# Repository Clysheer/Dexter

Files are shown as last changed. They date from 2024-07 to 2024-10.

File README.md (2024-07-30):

# Dexter
El proyecto consiste en la construcción de un robot autónomo capaz de navegar por un laberinto utilizando una combinación de hardware y software especializado. El robot estará equipado con un sensor de distancia VL6180X, el cual será fundamental para detectar obstáculos y calcular distancias mientras se desplaza por el laberinto. Este sensor permitirá al robot tomar decisiones informadas sobre la dirección a seguir para evitar colisiones y encontrar la ruta más eficiente hacia la salida del laberinto.
Para controlar los movimientos del robot, se utilizarán motores Pololu de 6V, los cuales serán gestionados por un driver TA 6586. Este driver proporcionará la potencia necesaria para que los motores puedan desplazar el robot con precisión y control, permitiéndole moverse de manera suave y estable a través del laberinto.
La placa microprocesadora ESP32 será el cerebro del robot, encargada de procesar los datos del sensor de distancia y tomar decisiones en tiempo real para guiar al robot por el laberinto. Esta placa estará programada con algoritmos de navegación y control que permitirán al robot realizar maniobras complejas, como girar en esquinas y evitar obstáculos, con el objetivo de encontrar la salida del laberinto de la manera más rápida y eficiente posible.
Además, para garantizar la autonomía del robot durante su recorrido por el laberinto, se utilizará una batería de 600 miliamperios a 7.4 voltios. Esta batería proporcionará la energía necesaria para alimentar todos los componentes del robot, asegurando que pueda completar su misión sin interrupciones.

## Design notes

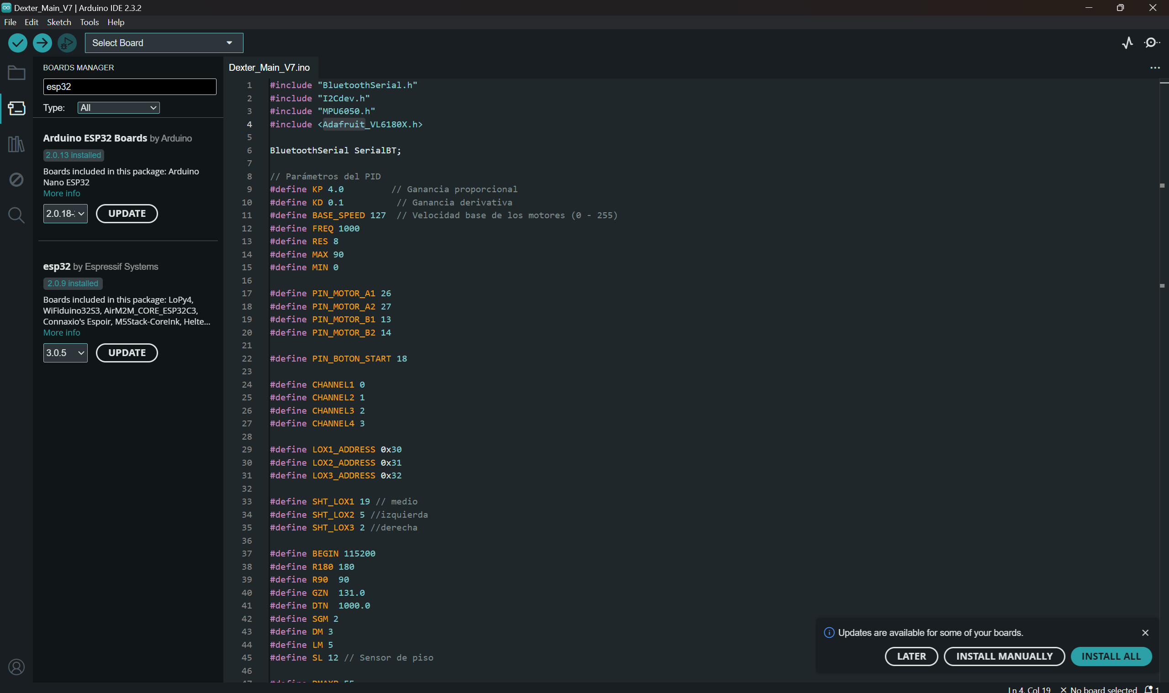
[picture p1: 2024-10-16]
Dexter_main/Dexter_Main_V7/BOARDMANAGE_ESP32.png

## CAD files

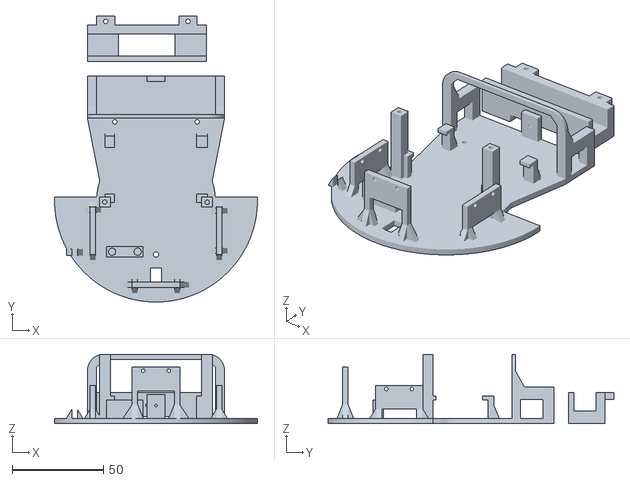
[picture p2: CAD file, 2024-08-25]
Dexter_3D/dexter v1.stl
111.0 x 156.4 x 38.0

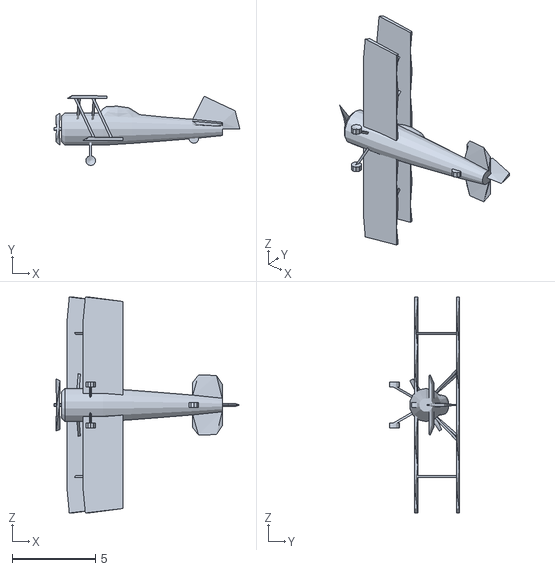
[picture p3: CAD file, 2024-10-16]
Dexter_Liberias/VL6180X/i2c_libreria/MPU6050/examples/MPU6050_DMP6_using_DMP_V6.12/MPUplane/data/biplane.obj
11.2 x 4.23 x 13.0

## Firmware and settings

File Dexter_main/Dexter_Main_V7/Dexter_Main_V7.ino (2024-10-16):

#include "BluetoothSerial.h"
#include "I2Cdev.h"
#include "MPU6050.h"
#include <Adafruit_VL6180X.h>
 
BluetoothSerial SerialBT;

// Parámetros del PID
#define KP 4.0         // Ganancia proporcional
#define KD 0.1          // Ganancia derivativa
#define BASE_SPEED 127  // Velocidad base de los motores (0 - 255)
#define FREQ 1000
#define RES 8
#define MAX 90
#define MIN 0

#define PIN_MOTOR_A1 26
#define PIN_MOTOR_A2 27
#define PIN_MOTOR_B1 13
#define PIN_MOTOR_B2 14

#define PIN_BOTON_START 18

#define CHANNEL1 0
#define CHANNEL2 1
#define CHANNEL3 2
#define CHANNEL4 3

#define LOX1_ADDRESS 0x30
#define LOX2_ADDRESS 0x31
#define LOX3_ADDRESS 0x32

#define SHT_LOX1 19 // medio
#define SHT_LOX2 5 //izquierda
#define SHT_LOX3 2 //derecha

#define BEGIN 115200
#define R180 180
#define R90  90
#define GZN  131.0
#define DTN  1000.0
#define SGM 2
#define DM 3
#define LM 5
#define SL 12 // Sensor de piso

#define DMAXP 55
#define DMAXD 85
#define DMAXI 80
#define DMAXM 100
#define DISTANCE1 0 
#define DISTANCE2 1 //
#define DISTANCE3 2 //izquierda
#define SCL 22
#define SDA 21

MPU6050 sensor;
  int16_t distance[DM] = {DISTANCE1, DISTANCE2,DISTANCE3};  // Arreglo para las distancias de los sensores (distance1, distance2,distance3)
  int16_t *dr = distance;


  // Valor RAW del giroscopio en el eje z
  int16_t gz;
  int16_t gy;
  int16_t gx;
  float gz_cal=0;
  long tiempo_prev, dt;
  float elapsedTime;
  float girosc_ang_z;
  float girosc_ang_z_prev;
  float angleZ = 0;  

  Adafruit_VL6180X lox1 = Adafruit_VL6180X();
  Adafruit_VL6180X lox2 = Adafruit_VL6180X();
  Adafruit_VL6180X lox3 = Adafruit_VL6180X();

  bool boton_presionado = false;
  float previousError = 0;


// Función de reposo
void reposo() {
  while (!boton_presionado) {
    if (digitalRead(PIN_BOTON_START) == LOW) {
      boton_presionado = true;
      delay(200);  // Anti-rebote
    }
  }
}

// Configurar los ID de los sensores

void setID() {
  digitalWrite(SHT_LOX1, LOW);
  digitalWrite(SHT_LOX2, LOW);
  digitalWrite(SHT_LOX3, LOW);
  delay(10);
  digitalWrite(SHT_LOX1, HIGH);
  digitalWrite(SHT_LOX2, HIGH);
  digitalWrite(SHT_LOX3, HIGH);
  delay(10);
  digitalWrite(SHT_LOX1, HIGH);
  digitalWrite(SHT_LOX2, LOW);
  digitalWrite(SHT_LOX3, LOW);
  Serial.println("no entro jajajaja");
 if (!lox1.begin()) while (1);
  lox1.setAddress(LOX1_ADDRESS);
  delay(10);
  Serial.println("A");
  digitalWrite(SHT_LOX2, HIGH);
  delay(10);

  if (!lox2.begin()) while (1);
  lox2.setAddress(LOX2_ADDRESS);
  digitalWrite(SHT_LOX3, HIGH);
  delay(10); 
  Serial.println("B");
  if (!lox3.begin()) while (1);
  lox3.setAddress(LOX3_ADDRESS);
  Serial.println("C");
}

void start_sensors() {
  sensor.initialize();  // Inicializa el MPU6050
  pinMode(PIN_BOTON_START, INPUT_PULLUP);
  pinMode(SHT_LOX1, OUTPUT);
  pinMode(SHT_LOX2, OUTPUT);
  pinMode(SHT_LOX3, OUTPUT);
  setID();
  calibrateMPU6050();
  tiempo_prev = millis();
  // Configuración de los pines de los motores
  ledcAttachPin(PIN_MOTOR_A1, CHANNEL1);
  ledcSetup(CHANNEL1, FREQ, RES);
  ledcAttachPin(PIN_MOTOR_A2, CHANNEL2);
  ledcSetup(CHANNEL2, FREQ, RES);
  ledcAttachPin(PIN_MOTOR_B1, CHANNEL3);
  ledcSetup(CHANNEL3, FREQ, RES);
  ledcAttachPin(PIN_MOTOR_B2, CHANNEL4);
  ledcSetup(CHANNEL4, FREQ, RES);
}

void readDistance(Adafruit_VL6180X &vl, uint16_t &distance) {
  uint16_t range = vl.readRange();
  distance = range;
}

void measurement(int16_t *dr) {
  uint16_t distance1, distance2, distance3;
  readDistance(lox1, distance1);
  *dr = distance1;
  readDistance(lox2, distance2);
  *(dr + 1) = distance2;
  readDistance(lox3, distance3);
  *(dr+ 2) = distance3;
}

void moveForward() {
  ledcWrite(CHANNEL1, MAX -45);  
  ledcWrite(CHANNEL2, MIN);
  ledcWrite(CHANNEL3, MAX);  
  ledcWrite(CHANNEL4, MIN);
}

void stopMotors() {
  ledcWrite(CHANNEL1, MIN);
  ledcWrite(CHANNEL2, MIN);
  ledcWrite(CHANNEL3, MIN);
  ledcWrite(CHANNEL4, MIN);
}
void moveLeft() {
  ledcWrite(CHANNEL1, MAX); 
  ledcWrite(CHANNEL2, MIN);
  ledcWrite(CHANNEL3, MIN);   
  ledcWrite(CHANNEL4, MAX);
}

void moveRight() {
  ledcWrite(CHANNEL1, MIN);   
  ledcWrite(CHANNEL2, MAX);
  ledcWrite(CHANNEL3, MAX);  
  ledcWrite(CHANNEL4, MIN);
}

// PID para el sensor VL6180X
void pidControl() {
  float error, derivative, pidOutput;

  error = DMAXP - distance[DISTANCE2];
  derivative = error - previousError;
  pidOutput = (KP * error) + (KD * derivative);
  previousError = error;

  int motorSpeedLeft = constrain(BASE_SPEED + pidOutput, MIN, MAX);
  int motorSpeedRight = constrain(BASE_SPEED - pidOutput, MIN, MAX);

  controlMotor(motorSpeedLeft, motorSpeedRight);
  delay(100);
}

void controlMotor(int speedLeft, int speedRight) {
  if (speedLeft > 0) {
    ledcWrite(CHANNEL1, speedLeft - 45);  
    ledcWrite(CHANNEL2, MIN);       
  } else {
    ledcWrite(CHANNEL1, MIN);       
    ledcWrite(CHANNEL2, abs(speedLeft)- 45);  
  }

  if (speedRight > 0) {
    ledcWrite(CHANNEL3, speedRight ); 
    ledcWrite(CHANNEL4, MIN);       
  } else {
    ledcWrite(CHANNEL3, MIN);       
    ledcWrite(CHANNEL4, abs(speedRight) );  
  }
}

// Función para rotar a un ángulo específico
void RRight(float degrees) {
  // Capturar el ángulo actual antes de rotar
  float targetAngle;  
  sensor.getRotation(&gx, &gy, &gz);
  angleZ += (gz - gz_cal) * (1.0 / 131.0); // Actualizar el ángulo acumulado
  targetAngle = angleZ + degrees; // Establecer el ángulo objetivo
  rotateRight();
  // Esperar hasta alcanzar el ángulo objetivo
  while (true) {
    sensor.getRotation(&gx, &gy, &gz);
    angleZ += (gz - gz_cal) * (1.0 / 131.0); // Actualizar el ángulo acumulado

    // Comprobar si se ha alcanzado el ángulo objetivo
    if ((degrees > 0 && angleZ >= targetAngle) || (degrees < 0 && angleZ <= targetAngle)) {
      stopMotors();
      break;
    }

    // Imprimir el ángulo actual
    Serial.print("Ángulo actual: ");
    Serial.println(angleZ);
    delay(100); // Espera un momento para evitar sobrecargar el serial
  }
}

void RLeft(float degrees) {
  // Capturar el ángulo actual antes de rotar
  float targetAngle;  
  sensor.getRotation(&gx, &gy, &gz);
  angleZ += (gz - gz_cal) * (1.0 / 131.0); // Actualizar el ángulo acumulado
  targetAngle = angleZ + degrees; // Establecer el ángulo objetivo
  rotateLeft();
  // Esperar hasta alcanzar el ángulo objetivo
  while (true) {
    sensor.getRotation(&gx, &gy, &gz);
    angleZ += (gz - gz_cal) * (1.0 / 131.0); // Actualizar el ángulo acumulado

    // Comprobar si se ha alcanzado el ángulo objetivo
    if ((degrees > 0 && angleZ >= targetAngle) || (degrees < 0 && angleZ <= targetAngle)) {
      stopMotors();
      break;
    }

    // Imprimir el ángulo actual
    Serial.print("Ángulo actual: ");
    Serial.println(angleZ);
    delay(100); // Espera un momento para evitar sobrecargar el serial
  }
}
// Función para girar a la derecha
void rotateRight() {
  ledcWrite(CHANNEL1, MIN); 
  ledcWrite(CHANNEL2, MAX);
  ledcWrite(CHANNEL3, MAX - 55);   
  ledcWrite(CHANNEL4, MIN);
  SerialBT.println("Girando a la derecha");
}

// Función para girar a la izquierda
void rotateLeft() {
  ledcWrite(CHANNEL1, MAX); 
  ledcWrite(CHANNEL2, MIN);
  ledcWrite(CHANNEL3, MIN);   
  ledcWrite(CHANNEL4, MAX - 55);
  SerialBT.println("Girando a la izquierda");
}

void calibrateMPU6050() {
  const int calibrations = 2000;
  float sumGz = 0;

  Serial.println("Calibrando el MPU6050...");
  for (int i = 0; i < calibrations; i++) {
    sensor.getRotation(&gx, &gy, &gz);
    sumGz += gz;
    delay(3);
  }
  gz_cal = sumGz / calibrations;
  Serial.println("Calibración completada.");
}
enum estadosMovimiento
{
  PISODETECTADO,
  MOVEFORWARD,
  ROTATEL90,
  ROTATER90,
  ROTATE180
};

void movements() { 
    int8_t piso = digitalRead(SL);
    estadosMovimiento state; 
    measurement(distance);
    if (piso == HIGH){  
        SerialBT.println("Entrando en caso: PISODETECTADO");
        state = PISODETECTADO;  //detecta piso
    }
    else if (distance[DISTANCE3] > DMAXI && distance[DISTANCE1] > DMAXM && distance[DISTANCE2] < DMAXD  ) { 
        SerialBT.println("Entrando en caso: MOVEFORWARD");  //detecta derecha
        state =  MOVEFORWARD ;   
    }
    else if (distance[DISTANCE3] > DMAXI && distance[DISTANCE1] < DMAXM && distance[DISTANCE2] < DMAXD ) {  
        SerialBT.println("Entrando en caso: ROTATEL90");//detectan medio y derecha 
        state = ROTATEL90 ;  //rotatel90 
    }
   else if (distance[DISTANCE3] < DMAXI && distance[DISTANCE1] > DMAXM && distance[DISTANCE2] < DMAXD ) { 
        SerialBT.println("Entrando en caso: MOVEFORWARD");  //detectan izquierda y derecha  
        state =  MOVEFORWARD;  
    }
    else if (distance[DISTANCE3] < DMAXI && distance[DISTANCE1] < DMAXM && distance[DISTANCE2] > DMAXD ) { 
        SerialBT.println("Entrando en caso: ROTATER90");  //detectan medio y izquierda 
        state = ROTATER90;  //ROTATER90  
    }
    else if (distance[DISTANCE3] < DMAXI && distance[DISTANCE1] > DMAXM && distance[DISTANCE2] > DMAXD ) {
        SerialBT.println("Entrando en caso: ROTATER90");   //detectan izquierda 
        state = ROTATER90 ;   //ROTATER90 
    }
    else if (distance[DISTANCE3] > DMAXI && distance[DISTANCE1] < 85 && distance[DISTANCE2] > DMAXD ) { 
        SerialBT.println("Entrando en caso: ROTATEL90");  //detectan medio 
        state = ROTATEL90;   
    }
    else if (distance[DISTANCE3] < DMAXI && distance[DISTANCE1] < DMAXM && distance[DISTANCE2] < DMAXD) { 
        SerialBT.println("Entrando en caso: ROTATEL90");  //detectan todos 
        state = ROTATEL90;  
    }
    else if (distance[DISTANCE3] > DMAXI && distance[DISTANCE1] > DMAXM && distance[DISTANCE2] > DMAXD ) {  
        SerialBT.println("Entrando en caso: ROTATER90"); // no detecta ninguno 
        state = ROTATER90;   
    }
   switch (state) {
        case PISODETECTADO: 
            Serial.println("Entrando en caso: PISODETECTADO");
            stopMotors(); 
            break; 
        case MOVEFORWARD: 
            Serial.println("Entrando en caso: MOVEFORWARD");
            pidControl();
            break;
        case ROTATEL90:  
            Serial.println("Entrando en caso: ROTATEL90");
            sendData();
             if(distance[DISTANCE1] > 40){
              moveForward();
              delay(250);
            }
            RLeft(90);
            break;
        case ROTATER90:  
            Serial.println("Entrando en caso: ROTATER90");
            sendData(); if(distance[DISTANCE1] > 40){
              moveForward();
              delay(250);
            }
            RRight(-90);
            break;
        case ROTATE180: 
            Serial.println("Entrando en caso: ROTATE180");
            sendData();
             if(distance[DISTANCE1] > 40){
              moveForward();
              delay(250);
            }
            RLeft(180);
            break; 
    }
} 

void start() {
  Serial.begin(115200);
  Wire.begin();
}

void setup() {
  start();
  start_sensors();
  SerialBT.begin("MiRobot");  // Nombre del dispositivo Bluetooth
  reposo();
}

void loop() {
  movements();
  sendData();
}

void sendData() {
  SerialBT.print("Distancia 1: "); SerialBT.println(distance[0]); //medio
  SerialBT.print("Distancia 2: "); SerialBT.println(distance[1]); //derecha
  SerialBT.print("Distancia 3: "); SerialBT.println(distance[2]); //izquierda
  
  sensor.getRotation(&gx, &gy, &gz);
  SerialBT.print("Giro Z: "); SerialBT.println(gz - gz_cal);  // Enviar el valor corregido
  int8_t piso = digitalRead(SL);
  SerialBT.print("Sensor de piso: "); SerialBT.println(piso);
}

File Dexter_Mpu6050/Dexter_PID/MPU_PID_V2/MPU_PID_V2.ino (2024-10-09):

#include <Wire.h>
#include "MPU6050.h"

// Parámetros del PID
#define KP 1.9          // Ganancia proporcional
#define KD 0.3          // Ganancia derivativa
#define BASE_SPEED 127  // Velocidad base de los motores (0 - 255)
#define PIN_BOTON_START 18
// Pines de los motores y canales PWM
#define FREQ 1000
#define RES 8
#define MAX 100
#define MIN 0

#define PIN_MOTOR_A1 26
#define PIN_MOTOR_A2 27
#define PIN_MOTOR_B1 13
#define PIN_MOTOR_B2 14

#define CHANNEL1 0
#define CHANNEL2 1
#define CHANNEL3 2
#define CHANNEL4 3

bool boton_presionado = false;
// Pines del MPU6050
MPU6050 sensor;
// Variables del giroscopio
int16_t gx, gy, gz;
float gx_cal = 0, gy_cal = 0, gz_cal = 0;

// Variables de tiempo
unsigned long previousTime = 0;
float elapsedTime;

// Variables de ángulo
float anglez = 0;
float previousAngleY = 0;

// Variables PID
float targetAngle = 0;  // Ángulo objetivo en grados
float error;
float previousError = 0;
float pidOutput;
float derivative;

void reposo() {
  // Espera hasta que el botón sea presionado
  while (!boton_presionado) {
    if (digitalRead(PIN_BOTON_START) == LOW) { // Verificar si el botón está presionado (LOW)
      boton_presionado = true;
      delay(200);  // Evitar debounce con un retraso
    }
  }
}

void setup() {
  Wire.begin();
  Serial.begin(9600);
  sensor.initialize();

  // Configurar el pin del botón como entrada con pull-up interno
  pinMode(PIN_BOTON_START, INPUT_PULLUP);

  // Verificar conexión con el sensor
  if (!sensor.testConnection()) {
    Serial.println("Error al conectar con el MPU6050");
    while (1);
  }

  calibrateMPU6050();

  // Configuración de los pines y canales de los motores
  ledcAttachPin(PIN_MOTOR_A1, CHANNEL1);
  ledcSetup(CHANNEL1, FREQ, RES);
  ledcAttachPin(PIN_MOTOR_A2, CHANNEL2);
  ledcSetup(CHANNEL2, FREQ, RES);
  ledcAttachPin(PIN_MOTOR_B1, CHANNEL3);
  ledcSetup(CHANNEL3, FREQ, RES);
  ledcAttachPin(PIN_MOTOR_B2, CHANNEL4);
  ledcSetup(CHANNEL4, FREQ, RES);

  previousTime = millis();
}

void loop() {
  reposo(); // Espera a que el botón sea presionado para iniciar el código

  unsigned long currentTime = millis();
  elapsedTime = (currentTime - previousTime) / 1000.0;  // Convertir a segundos
  previousTime = currentTime;

  readMPU6050();

  // Cálculo del ángulo actual en el eje Y
  anglez += (gz / 131.0) * elapsedTime;

  // Cálculo del error y derivada
  error = targetAngle - anglez;
  derivative = (error - previousError) / elapsedTime;

  // Calcular la salida PID
  pidOutput = (KP * error) + (KD * derivative);
  previousError = error;

  // Calcular velocidades de los motores ajustadas con la señal PID
  int motorSpeedLeft = constrain(BASE_SPEED - pidOutput, MIN, MAX);
  int motorSpeedRight = constrain(BASE_SPEED + pidOutput, MIN, MAX);

  // Controlar los motores con las velocidades calculadas
  controlMotor(motorSpeedLeft, motorSpeedRight);

  // Imprimir valores en el Serial Monitor
  Serial.print("Ángulo z: ");
  Serial.print(anglez);
  Serial.print(" grados | ");
  
  Serial.print("PID Output: ");
  Serial.print(pidOutput);
  Serial.print(" | ");

  Serial.print("Velocidad Motor Izquierdo: ");
  Serial.print(motorSpeedLeft);
  Serial.print(" | ");

  Serial.print("Velocidad Motor Derecho: ");
  Serial.println(motorSpeedRight);

  delay(100);  // Retardo de 100 ms
}

void calibrateMPU6050() {
  const int calibrations = 2000;
  float sumGz = 0;

  Serial.println("Calibrando el MPU6050...");
  for (int i = 0; i < calibrations; i++) {
    sensor.getRotation(&gx, &gy, &gz);
    sumGz += gz;
    delay(3);
  }
  gz_cal = sumGz / calibrations;
  Serial.println("Calibración completada.");
}

void readMPU6050() {
  sensor.getRotation(&gx, &gy, &gz);
  gz -= gz_cal;
}

void controlMotor(int speedLeft, int speedRight) {
  // Controla el motor izquierdo
  if (speedLeft > 0) {
    ledcWrite(CHANNEL1, speedLeft); // Motor A1 adelante
    ledcWrite(CHANNEL2, MIN);       // Motor A2 apagado
  } else {
    ledcWrite(CHANNEL1, MIN);       // Motor A1 apagado
    ledcWrite(CHANNEL2, abs(speedLeft)); // Motor A2 en reversa
  }

  // Controla el motor derecho
  if (speedRight > 0) {
    ledcWrite(CHANNEL3, speedRight); // Motor B1 adelante
    ledcWrite(CHANNEL4, MIN);       // Motor B2 apagado
  } else {
    ledcWrite(CHANNEL3, MIN);       // Motor B1 apagado
    ledcWrite(CHANNEL4, abs(speedRight)); // Motor B2 en reversa
  }
}

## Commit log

2024-08-25 add 3d desing
    add 3d desing
    [dexter v1.stl]
2024-10-16 add codigo final funcional
    soy alto capo y termine el codigo
2024-10-16 add i2c
